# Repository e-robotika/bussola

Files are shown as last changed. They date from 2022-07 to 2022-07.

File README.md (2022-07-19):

# geo:bit
Digital geological compass using micro:bit, and 3D printed case.

Accuracy average 3 degrees re. magnetic North

Accuracy clinometer better than 1 degree.

Uses 5x5 led display to display data fast, first column shows 100's, second and third column 10's, last two columns show 1's : example:

0 0 0 1 0 

0 1 0 1 0

0 1 0 1 1

1 1 0 1 1

1 1 0 1 1

which reads 248

python code can be adapted to suit needs, inlcuding strike dip, declination.

future code adaptations could include;
- average readings to increase accuracy
- adding data storage
- adding gps
- bluetooth data connection to mobile device
- sound, or speach
- etc

user guide included, building instructions in *introduction.pdf*, also on instructables,
3d printable casing (stl files) on thingiverse

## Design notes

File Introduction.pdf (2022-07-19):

Introduction
Looking for a new geologic compass for my students, I tested and compared a number of cheap and expensive compasses. Size, shape, readability, stability, accuracy, durability, and definitely price, all types have their pro's and con's and none of them matched my preferences.
Digital geological compasses are rare and expensive. Many good, and not so good mobile phone apps have been reported and tested by experts. But no mobile phone has a functional design that allows straightforward understanding of what it is you are actually measuring, which is important in teaching students geology in the field. So why not make your own, ideal, geological compass, matching your own needs. It turns out to be quite as accurate as most affordable geological compasses, (+- a few degrees), easily adaptable (declination, strike/dip direction/dip angle) and it is cheaper than any semi-decent geological compass, with his example costing less than €30,- And last but not least, it is fun to make. Geo:bit is a geologic compass using a micro:bit circuit board.

Parts/supply
Micro:bit (https://microbit.org/) (I used the old type)
Battery socket holder (https://nl.aliexpress.com/item/1005001847447819.html)
Two mini spirit levels (https://nl.aliexpress.com/item/4001181017657.html)
Power cell, CR2032
Small screws, non magnetic, I used nylon screws, M2.5) (https://nl.aliexpress.com/item/32881183627.html) 3D printer
Small file or sandpaper
Soldering iron

Description
Geo:bit Design choices, Shape factor
I am quite picky when it comes to geological compasses, I prefer a flat lid, that van be places directly on the strata, it should open completely flat, to allow measuring sub-horizontal layers. I prefer dip direction/dip angle over strike - dip. It should fit in a breast pocket, it should stabilize fast and readability is important. Geo:bit is a geologic compass build on a micro:bit circuit board. My prototype weighs exactly 57 grams, with fully charged batteries. It measures 60 * 76 * 24 mm. The casing was printed using PLA material. The casing was designed using Sketchup Pro.
The Micro:bit is fitted back to front, so that the micro usb port is still reachable, thus button A is on the right side, and button B is left.
A power switch is included in the battery socket, so it only consumes power when in use. Two spirit levels have been incorporated in the base, allowing to check horizontality when power is off. These are not strictly necessary, as the geo:bit provides an excellent spirit level when powered on.
We should avoid magnetic materials as much as possible, therefore the battery was placed as far away from the sensor as possible, and a plastic hinge was used.
A measuring scale was printed on the side, in centimeters as well as 90, 45 and 0 degree opening of the lid.

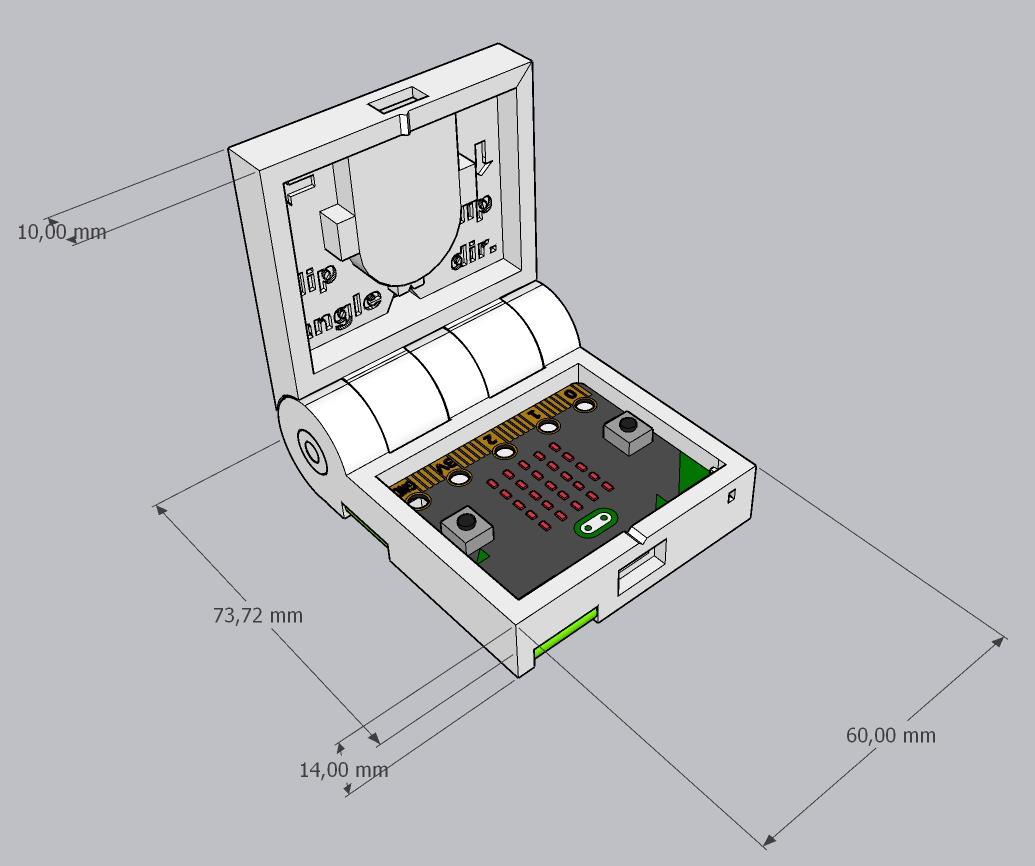
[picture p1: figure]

Design choices, Electronics
I choose Micro:Bit since it has all needed sensors and a 5 * 5 led matrix on a single board, which makes it more rugged than when all kind of components need to be combined. It operates on a single CR2032 battery batteries for a very, very long time. I cannot tell how long, since it has never run out of power yet.
The led display is capable of scrolling text, however, reading scrolling text of three digits is annoying and appears to take ages. So I developed a way for the led matrix to instantaneous show numbers up to 599, we only need 360 degrees max anyway. We have five columns of five leds each. The first column on the left shows 100's, the second and third column show 10's, and the fourth and fifth column show units. It takes a bit of practice, but it can be read quickly, allowing the compass to continuously take measurements while displaying the bearings in real time.

It is well possible to program a digital compass such that the compass automatically measures its own position (Zobl et al., 2007), and returns dip direction and dip of the plane it is on, without manually orientating it to horizontal, or vertical position, to measure dip direction and dip angle respectively. I deliberately choose to mimic a classic compass, for educational purposes, thus the user sees what they measure, and dip direction and dip angle are not just abstract numbers.

Construction
Step 1. Print the base, lid and hinge pin and flanges of the compass using a 3D printer. Using sand paper and or a small file, remove irregularities and make the hole for the hinge large smooth for the pin to easily move. Remove material so that the knuckles fit snugly, and the lid can be opened a full 180 degrees. Place pin through knuckles and and use hot soldering iron to melt the flanges to the pin on each end of the pin.
Connect Mirobit:bit to batteries, I guided the wires through the hole next to GND and soldered them to the back. Place the battery in the holder, and solder the wires to GND and 3V of the micro:bit. Make sure to connect the copper pads to the copper rings surrounding the holes, if you solder the wires to the back of the Micro:bit. (https://tech.microbit.org/hardware/powersupply/). You can glue the battery socket in place, but it fits quite snuggly.
Step 2. Push Micro:bit in place, and fix in place with some nylon screws. Drill some holes corresponding to the centre of each hole of Micro:bit and fasten in place. It should fit exactly. Make sure the Micro:bit is placed correct, the sides of Micro:bit are parallel to the casing, and when placed on a horizontal surface the central led should be on. If not, then adjust mounting, since a good alignment of Micro:bit and casing are essential for accuracy. Lastly, you may attach a lanyard through the holes in the right corner of the base.
Step 3. Connect your micro:bit to your computer using a usb (data) cable. Open the code in Mu editor(https://codewith.mu/), or any other editor capable of processing micropython for micro:bit. You can adapt the code to your needs if you want. Save a compiled .hex file on your micro:bit, or flash it directly from the Mu- editor. The yellow on LED on the bottom of the micro:bit starts flashing when code is uploaded. When complete the code is executed automatically. When new code was flashed a calibration sequence will automatically start to calibrate the micro:bit's inbuild magnetometer. This requires the user to tilt and rotate the compass in three dimensions to fill the screen. The compass measures the magnitude of the magnetic field in different orientations to calculate a reference model for your specific micro:bit. Calibration can be started at any moment by pressing button A and B simultaneously. When calibration is successful, a smiley ;) is shown and the compass enters level mode. A single led on the 5x5 display is on, mimicking a spirit level. If the micro:bit is horizontal, the central led is lit. Tolerance levels for the horizontality can be adjusted in the programme.
In the micropython code, the following parameters can be modified:
- Brightness: intensity of LED display, default 9 = maximum brightness
- Declination: magnetic declination, default = 0
When power switched on a short animation will indicating the micro:bit is ready. I got used to reading measurement on the led display quickly.

The user manual describes field use of the compass.

Testing and evaluating the compass

I used a Micro:Bit, since it is easy to programme in microPython, and it is a single board, low voltage, so less batteries, and it has a build-in accelerometer, magnetometer and LED display. The design can be adapted to Arduino, but would require addition of additional components, including magnetometer, a display and an accelerometer.
Field test have been limited so far, but initial tests showed fast response, no need to wait for the compass needle to stop swinging. Good readability of the display, and a decent accuracy. Measurements were compared to a Brunton and a Recta compass. For dip angle, or inclination, the geo:bit is very precise and average error is 0 degree, beating the competition in readability. Accuracy is 3.8 degrees on average for magnetic measurements. A filtering routine taking the average of a number of readings, could further improve this, since the noise is often 2 - 3 degrees. Digital compasses need to calibrate, the algorithm for calibration of micro:bit is open source and has been greatly improved since the first versions. However, sometimes the calibration fails and the readings can be 90 degrees off. This occasionally happens to mobile phones but also to Micro:bit. The good news is that it is always a large error, so you know your compass is off, a recalibration solves the issue.
Figure shows accuracy without filtering. Average error is 3.8 degree, maximum error can be up to 8 degrees. Difference is measured every 5 degrees, and compared to a Brunton Axis Transit compass.

A more rigorous field test will be conducted soon. An assessment of accuracy in comparison to other devises needs to be performed as outlined by Novakova and Pavlis, 2019. Furthermore an assessment of accuracy over time as described by Almendiger et al., 2017 will give insight in the sensitivity to external disturbances. Battery life is great, two weeks on a new CR 2032 battery.

Modifications
The compass can easily be modified to cater for different needs, including a more rugged, waterproof casing, a rechargeable battery, data logging, or transmission using bluetooth, an e-paper display, spoken measurements, and if you really want, taking strike dip measurements rather than dip - dip direction.

References:
L. Novakova and T. L . Pavlis, 2019, Modern Methods in Structural Geology of Twenty-first Century: Digital Mapping and Digital Devices for the Field Geology. In: Teaching Methodologies in Structural Geology and Tectonics (pp.43-54), DOI:10.1007/978-981-13-2781-0_3
R. Almendiger, C. R. Siron, and C. Scott, 2017, Structural data collection with mobile devices: Accuracy, redundancy, and best Journal of Structural Geology 102, DOI:10.1016/j.jsg.2017.07.011

0

2

4

6

8

10

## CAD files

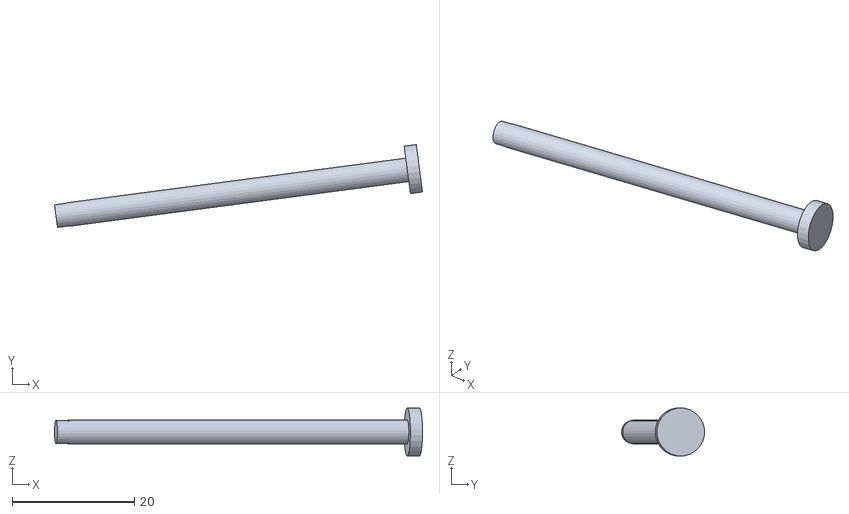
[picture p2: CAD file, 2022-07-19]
geobt hinge pin.stl
60.2 x 13.6 x 7.83

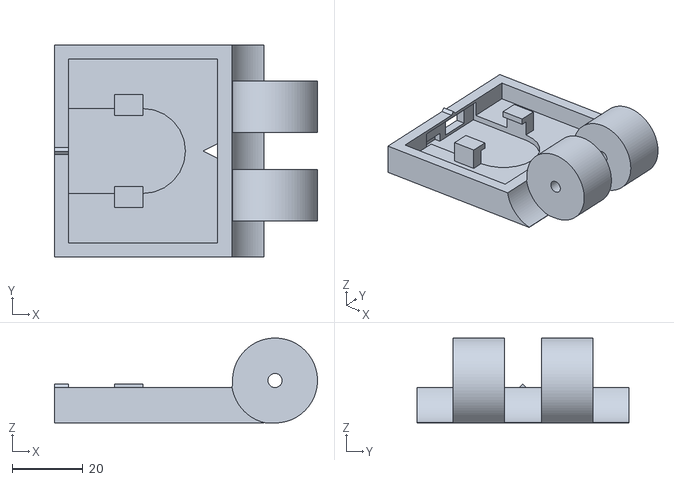
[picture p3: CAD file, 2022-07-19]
geobit lid.stl
74.3 x 60.0 x 24.0

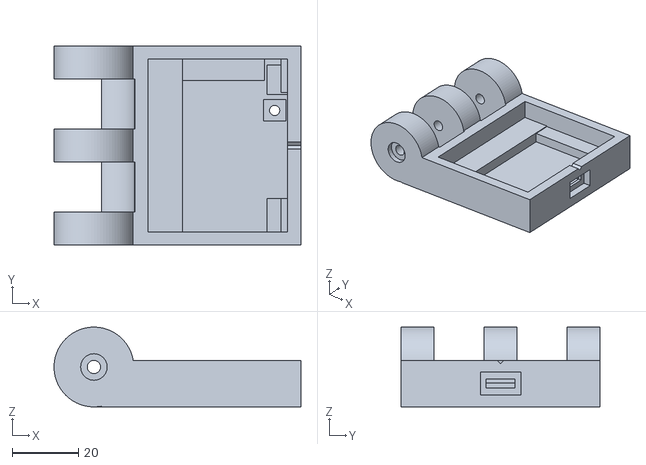
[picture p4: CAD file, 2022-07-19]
geobit base.stl
74.3 x 60.0 x 24.0

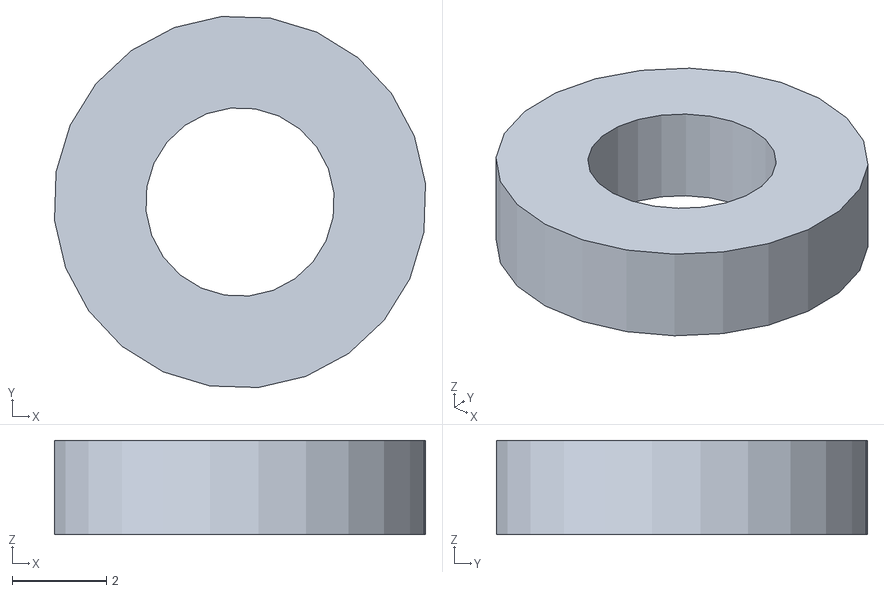
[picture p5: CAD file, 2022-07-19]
geobit ring.stl
7.86 x 7.86 x 2.00

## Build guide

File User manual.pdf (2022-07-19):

## User manual

## Geo:bit Digital Geological Compass

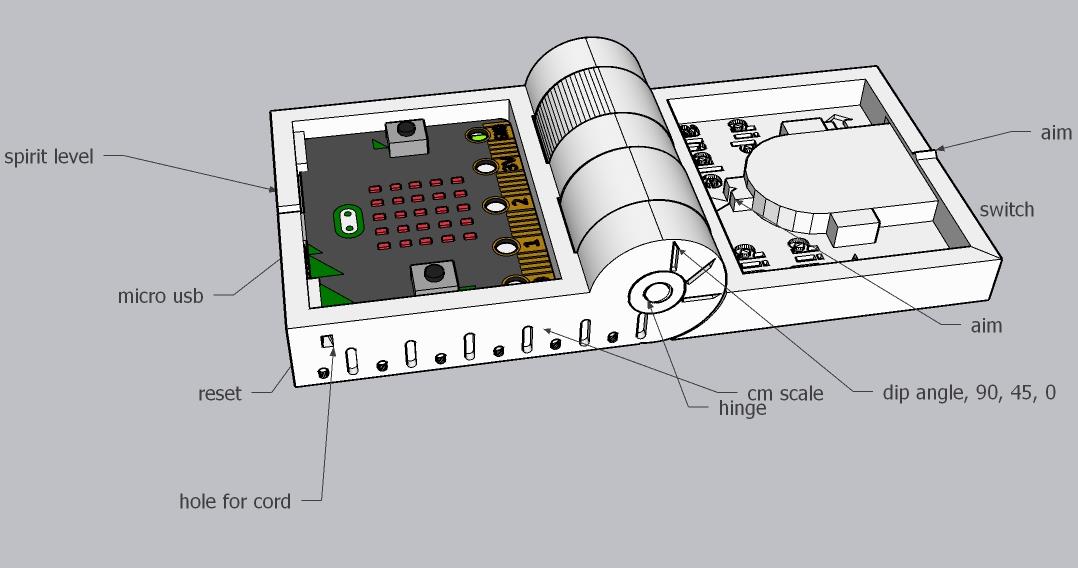
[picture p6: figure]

### Table of Contents

Getting to know your compass Components

Calibration

Using the compass
Taking a bearing

How to read led display

Measuring the orientation of a plane

Measing dip direction dip angle

Measuring lineations

### Getting to know your compass

When power is switched on, using the switch on the battery holder, a starting sequence is shown on the 5 * 5 display. After that, the compass is in spirit level mode, and one led is lit mimicking a spirit level. After use, switch of the power and close lid.

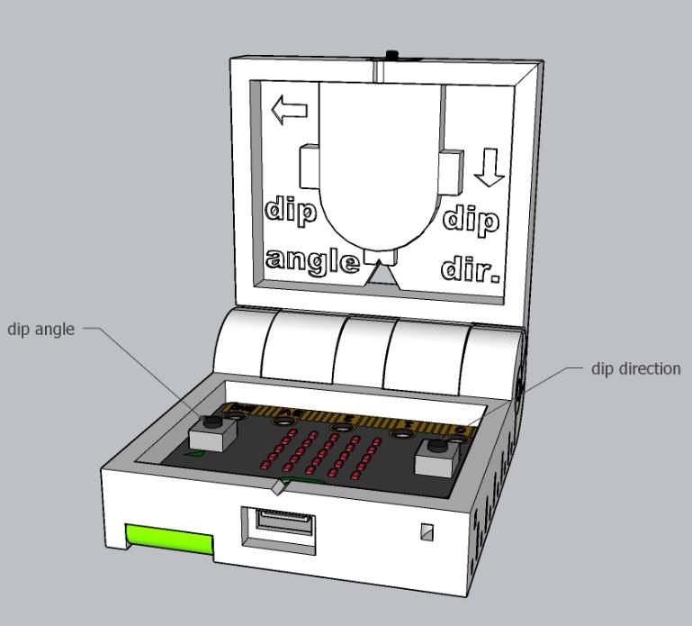
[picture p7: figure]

Power is supplied from CR2032 power cell, stored in the lid, as far as possible from the magnetic sensor on the micro:bit. The batteries can easily be replaced.

Three triangular sights in the compass casing help shooting a bearing. See section taking a bearing below)

A micro usb port is present on the front of the compass, a hole to access the micro;bit reset button is located on the bottom of the compass.

A ruler is printed on the right side of the base.

Calibration
We use the build in magnetometer of the micro:bit to measure the magnetic field. Micro:bit measures three axes of the magnetic field and calculates the North direction from those. Before first use the compass must be calibrated, using the build-in calibration sequence, that requires rotating and tilting the compass in all directions so all the LEDs on the display are on. It is advised to check the calibration with an analogue compass. Calibration can be reinitiated at any time by pressing button A and B at the same time. The calibration is stored in Micro:bit’s memory and remains there even when power is switched of. Resetting Micro:bit using the reset button, requires a new calibration.

The calibration algorithm has been published by Lancaster University on Github, and appears to be working well. However, it is always advisable to double check the calibration on a regular base.

Important is to calibrate the compass with the battery socket in place, since movement of metal objects will have an impact on the magnetic readings. Further, it is recommended to calibrate in the absence of metal objects, outdoors, away from magnetic interference from cars, mobile phone, power lines etc..

Declination of the True North from the geographical North can be programmed in the geo:bit’s programme, its default is set to 0 degrees.

Figure 1:geo:bit, functions of the buttons

### Using the compass

Bearing
The geo:bit compass can be used to shoot a bearing in the field. By aligning sights 1, 2 and 3 or 4 in a straight line, pressing button A, will display the direction of that vector, from the compass towards the user, if the direction of a far away object is needed with respect to the user, 180 degrees should be added or subtracted.

In a similar fashion inclination can be measured, using button B and viewing parallel to the long
side of an open compass.

Reading the LED display

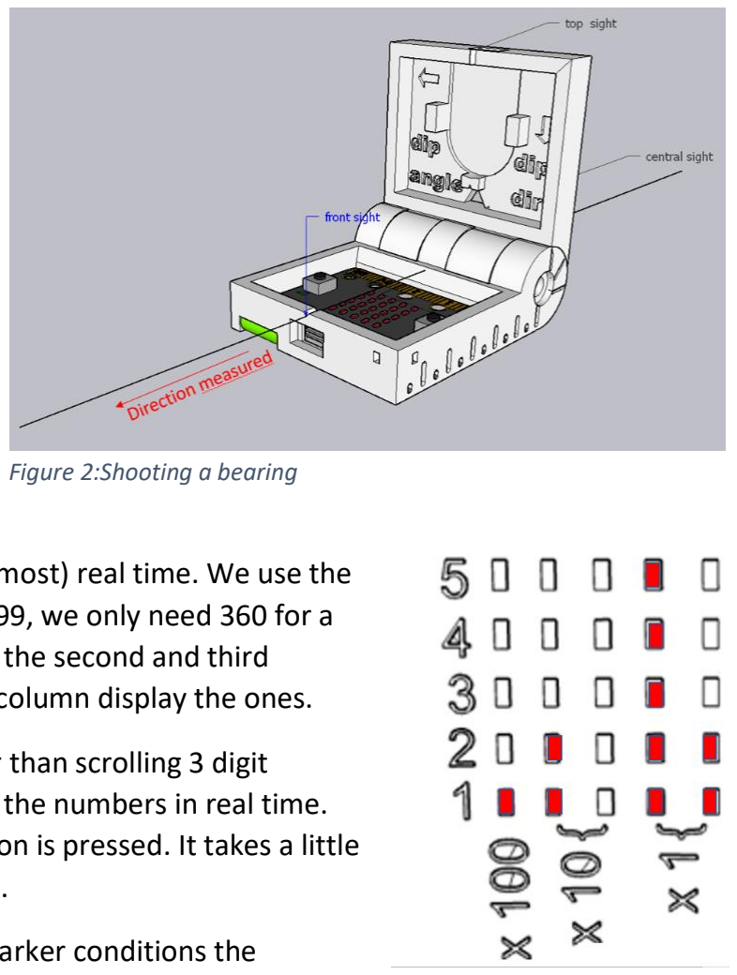
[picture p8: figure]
Figure 2:Shooting a bearing

The led display is designed to display values in (almost) real time. We use the 25 LEDs as a bar graph, showing numbers up to 599, we only need 360 for a compass. The first column displays the hundreds, the second and third column display the ten’s and the fourth and fifth column display the ones.

This method of displaying numbers is much faster than scrolling 3 digit numbers across the display, and allows to display the numbers in real time. Real time values are displayed as long as the button is pressed. It takes a little bit of practice to read the numbers in this fashion.

Even in direct sunlight the LEDs are readable, in darker conditions the readability surpasses that of a normal compass.

Waterproof
The compass is not waterproof, and care should be taken when using it in wet conditions, water can permanently damage the electronic components of the compass.

Figure 3: Example of the LED display showing the number 127

Orientation of planar features
There are two often used methods for defining the orientation of a plane in space. Strike / dip measures the orientation of a horizontal line in the plane we want to define, in the figure below, that is either to left or to the right. Often the right hand rule is applied, meaning that if you put your right hand with the palm on the strata, fingers pointing down dip, then your thumb indicates the strike direction.

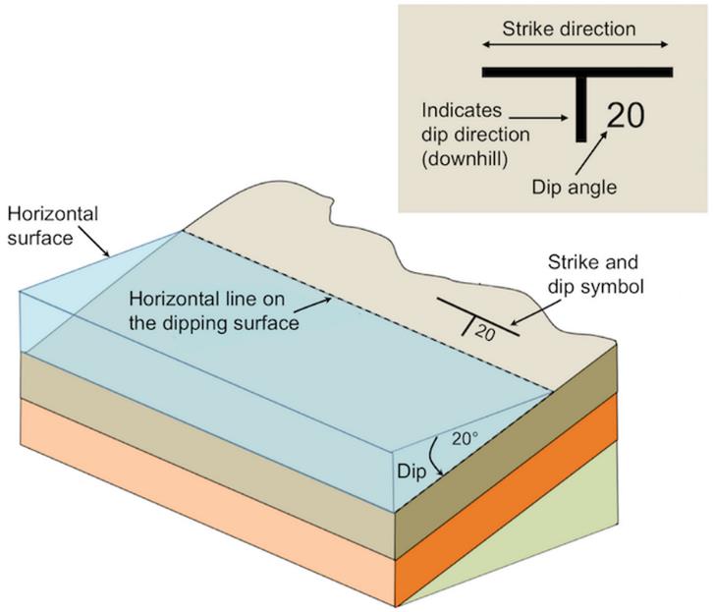
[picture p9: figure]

This compass uses dip direction, as indicated in the figure, which is the steepest line in a plane, and by definition perpendicular to the strike, and pointing downwards. The compass can easily be adapted to show strike by subtracting 90 degrees.

I favour dip direction and dip angle, but realise that many American text books use strike dip.

Dip angle is a measure of the steepness of a plane, and measures the angle between the

horizontal and the steepest line. It is very important to measure the dip angle parallel to the dip direction, the steepest line.

To avoid confusion in field notes, my students write their measurements in the following format: S = XXX/YY, where S0 indicates the nature of the planar feature measured, sedimentary (S0), metamorphic or structural (S1 and further), then 3 digits for the dip direction, so 30Degrees NNE is written as 030, a slash and two digits for the dip angle.

Figure 4: Orientation of a plane, strike/ dip and dip direction/ dip angle, Source: Karla Panchuk (2018) CC BY 4.0.

Measuring orientation of a plane
When measuring the orientation of a sedimentary layer, metamorphic foliation or another planar feature, we open the compass, and place the lid on the plane we need to measure. While holding the lid on the plane, we rotate the compass until the base is horizontal. Similar to a spirit level or bubble level, we can rotate the compass base until the led is in the centre of the display (Fig. 1.).

The position of the led is based on readings of the gravitational field, by the build in accelerometer. X and Y axis should be zero, so that the micro:bit is perpendicular to the Z axis (Fig 2.) .

When the compass base is horizontal, the top of the compass lid is automatically horizontal (strike direction), and the sides of the lid, automatically indicate the steepest line in the plane we want to measure; the dip direction. The dip direction is pointing downwards towards the reader, along the arrow printed in the lid.

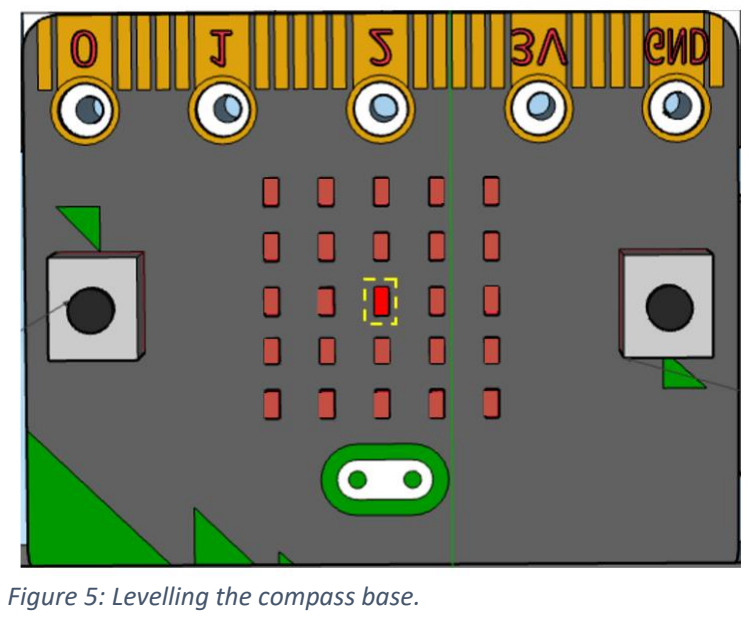
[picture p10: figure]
Figure 5: Levelling the compass base.

Holding the compass steady, with spirit led in the centre, we can press button A to read the orientation of the dip direction. As long as button is pressed the compass keeps reading and displaying the direction. See section X on how to read the display. The micro:bit reads the 3 directions of the internal magnetometer, and uses a calibration ellipsoid to determine the North. See section on calibration to calibrate the compass.

Reading the dip angle, is achieved by placing the compass on its side, with the lid fully opened, similar to using an analogue clinometer. The arrow printed on the lid, indicating dip angle points towards the rock surface.

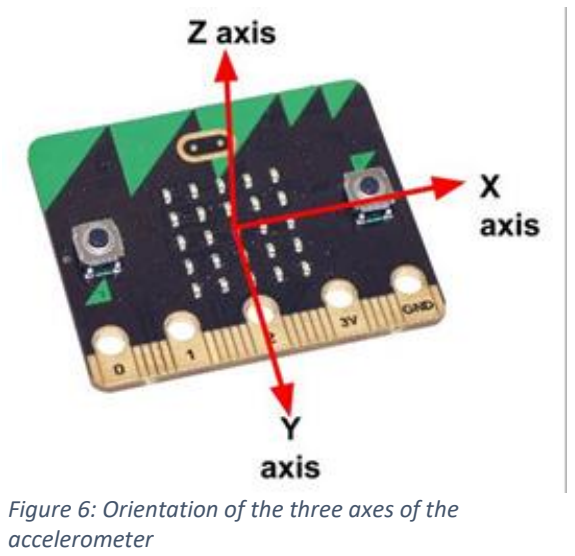
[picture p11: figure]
accelerometer
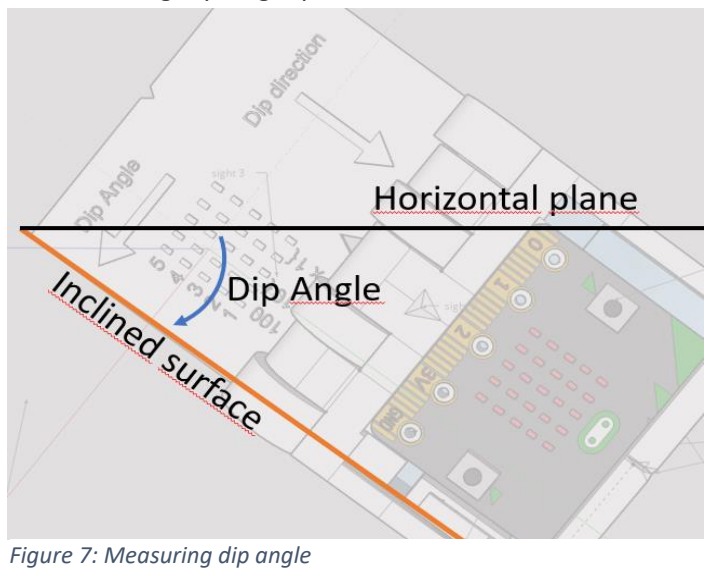
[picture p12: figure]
Figure 7: Measuring dip angle

Pressing micro:bit button B shows the dip angle. We can read the number displayed by the leds in a similar fashion to the dip direction. The dip angle is based on the ratio between the measurements of the accelerometer for the X and Y axis, and is very accurate.

Figure 6: Orientation of the three axes of the

Measuring a line
Place the side of the lid parallel to the lineation, while holding the side of the lid parallel to the line rotate and tilt the compass base until the spirit level led indicates horizontality. Then measure the plunge direction, by pressing Button A, the downward direction of the line is measured (0-360). The plunge, can be measured when the compass s completely opened and the long side of the compass is parallel to the line, and the compass is vertical, pressing button B yields the plunge (0-90).

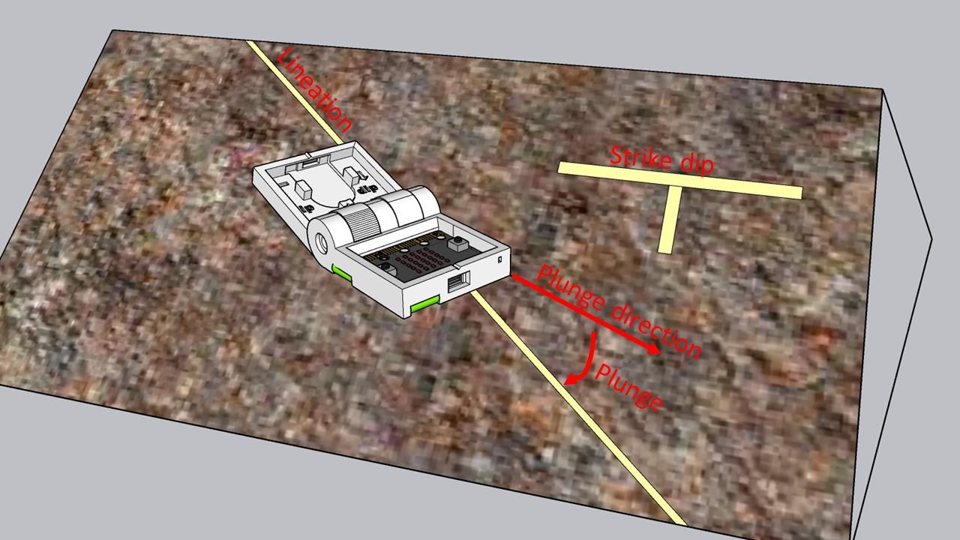
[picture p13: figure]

The digital geological compass is published using Creative Commons. Software (github) and design using Mu micropython editor and sketchup free for the casing. A prototype was printed by AUC 3D printing lab. Building instructions, and further technical details are published on Instructables.com. Please feel free to further develop this concept.
